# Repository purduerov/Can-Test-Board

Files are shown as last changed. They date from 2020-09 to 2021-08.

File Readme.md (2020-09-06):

# Readme for Can-Test-Board

Whenever you make a new part, download the datasheet and save it here _**and**_ with the part in the parts library

Always pull other people's changes before beginning to work
`git pull`

Be sure to push your changes after  working on them. Run:
1. `git add .` to add any files in this directory or a subdirectory
or `git add -u` to add any modified files
2. (Optional) `git clean -nX` to see what ignored files can be removed
	`git clean -fX` removes ignored files (Eagle backups)
3. `git commit -m "helpful commit message"` with a description of the work that you did
4. `git push` to push your work to github

Other helpful commands
* `git status` says information about modified and staged files
* `git log` shows the recent commits of the repository
* `git log filename.extension` show the recent commits for just that file
* `git checkout first-couple-letter-of-commit-id` lets you go back to a previous version
* `git checkout master` brings you back to the latest commit
* `git tag` lists the tags
* `git tag -a orderX -m "the version of the board placed for the X'th order"` tag a specific commit
* `git push --tags` needed to push tags to remote
* `git show orderX` show the commit log for the given tag
* `git checkout orderX` go back and interact with the files at the tagged commit

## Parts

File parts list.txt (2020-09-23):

Partlist

Exported from CAN-Test-Board.brd at 9/23/2020 9:46 AM

EAGLE Version 9.6.2 Copyright (c) 1988-2020 Autodesk, Inc.

Assembly variant: 

Part     Value          Package          Library                   Position (mil)        Orientation

C1       4.7uF          0603             SparkFun-Capacitors       (810 860)             MR270
C2       4.7uF          0603             SparkFun-Capacitors       (590 690)             MR90
C3       4.7uF          0603             SparkFun-Capacitors       (590 860)             MR270
C4       4.7uF          0603             SparkFun-Capacitors       (660 860)             MR270
C5       4.7uF          0603             SparkFun-Capacitors       (740 860)             MR270
C6       4.7uF          0603             SparkFun-Capacitors       (660 690)             MR90
C7       4.7uF          0603             SparkFun-Capacitors       (840 340)             MR180
C8       4.7uF          0603             SparkFun-Capacitors       (980 1160)            R0
C9       4.7uF          0603             SparkFun-Capacitors       (550 1160)            R180
C10      4.7uF          0603             SparkFun-Capacitors       (1160 1080)           MR270
C11      0.1uF          0603             SparkFun-Capacitors       (1120 1230)           R90
C12      100nF          0603             SparkFun-Capacitors       (700 1990)            MR90
C13      18pF           CAP_0603         Resistor_Capacitor        (1350 1870)           R270
C14      18pF           CAP_0603         Resistor_Capacitor        (1350 1440)           R90
C15      100nF          0603             SparkFun-Capacitors       (890 1480)            MR90
C16      4.7nF          0603             SparkFun-Capacitors       (1670 910)            MR270
C17      1.0uF          0603             SparkFun-Capacitors       (1620 1240)           R0
C18      1.0uF          0603             SparkFun-Capacitors       (1770 1320)           R90
D1                      LED-0603         SparkFun-LED              (1110 150)            R270
D2                      LED-0603         SparkFun-LED              (1010 150)            R270
J1                      1X12             SparkFun-Connectors       (90 100)              R90
J2                      1X12             SparkFun-Connectors       (1960 1190)           R270
J3                      1X05             SparkFun-Connectors       (370 1640)            R90
J4                      1X03             SparkFun-Connectors       (210 1570)            R270
J5                      1X03             SparkFun-Connectors       (80 1570)             R270
PCB1     RPI2           RPI2             MicrocontrollerComponents (2310 4300)           R180
R1       1k             0603             SparkFun-Resistors        (740 1120)            R270
R2       1k             0603             SparkFun-Resistors        (810 230)             MR270
R3       1k             0603             SparkFun-Resistors        (800 1120)            R270
R4       0              0603             SparkFun-Resistors        (1210 1750)           R180
R5       0              0603             SparkFun-Resistors        (640 1530)            R90
R6       60             0603             SparkFun-Resistors        (1640 1050)           MR0
R7       330            0603             SparkFun-Resistors        (1110 300)            R90
R8       60             0603             SparkFun-Resistors        (1640 1130)           MR180
R9       330            0603             SparkFun-Resistors        (1010 310)            R90
R10      60             0603             SparkFun-Resistors        (1010 1270)           R180
R11      60             0603             SparkFun-Resistors        (1010 1350)           R0
R12      10k            0603             SparkFun-Resistors        (1730 1450)           R180
R13      10k            0603             SparkFun-Resistors        (1730 1520)           R180
R14      0              0603             SparkFun-Resistors        (1480 1310)           R0
R15      0              0603             SparkFun-Resistors        (1730 1640)           R270
R19      0              0603             SparkFun-Resistors        (1210 1560)           R180
RESET                   SW_2512          DiscreteComponents        (610 350)             R0
SV1                     FE05-1           con-lsta                  (510 120)             R180
U$1      MCP2515        MCP2515          PI_Shield_Library         (1100 1660)           R90
U$2      TCAN337D       TCAN337D         PI_Shield_Library         (800 1560)            MR270
U$3      STM32F042K6T6  STM32F042K6T6    PI_Shield_Library         (590 940)             R270
U$4      T2I            T2I              Samtec t2i                (1880 240)            R180
U$5      NCP114         TSOP-5           LED_lib                   (1680 1380)           R270
U$8      TCAN337D       TCAN337D         PI_Shield_Library         (1270 1160)           MR180
Y1       ECS-80-S-4X    XTAL_ECS-80-S-4X ECS-80-S-4X               (770 1160)            MR0
Y2       ECS-80-S-4X    XTAL_ECS-80-S-4X ECS-80-S-4X               (1350 1660)           MR90

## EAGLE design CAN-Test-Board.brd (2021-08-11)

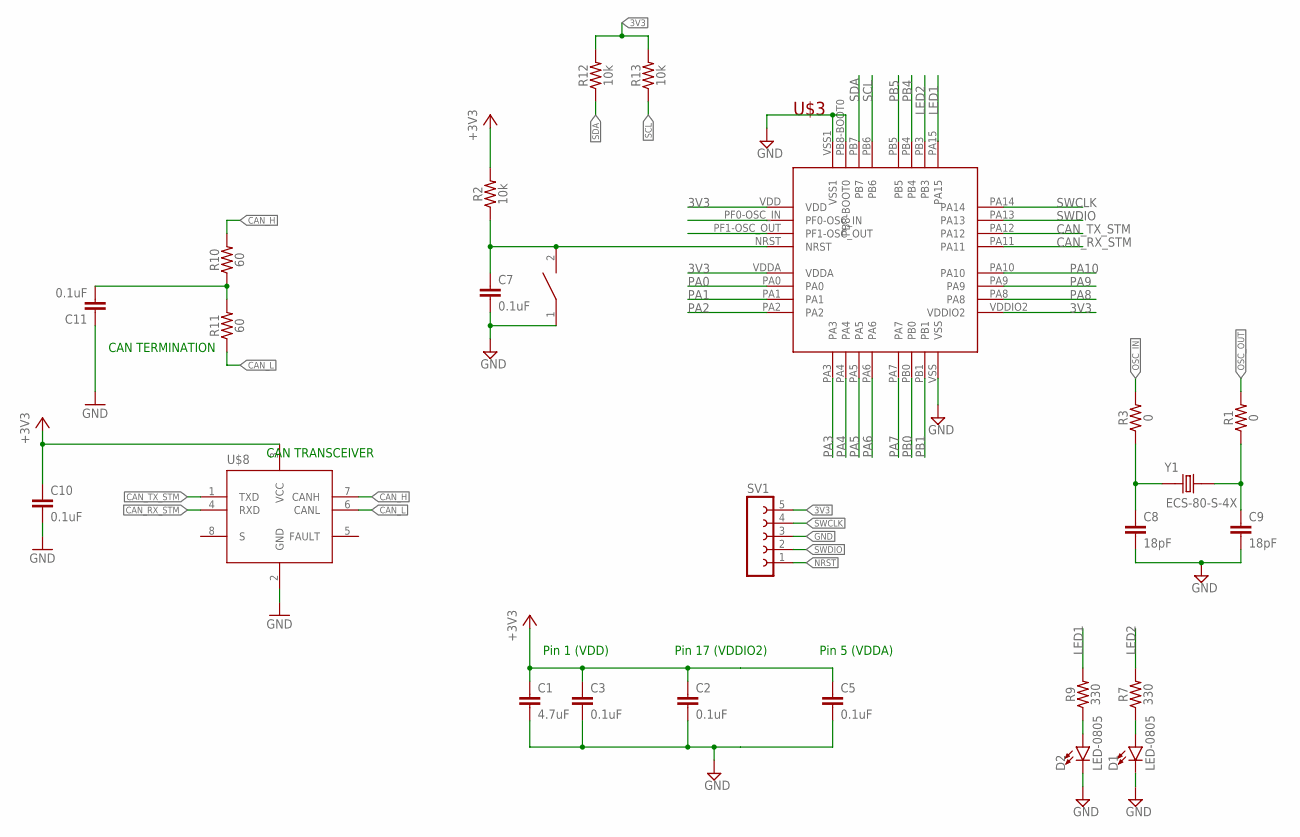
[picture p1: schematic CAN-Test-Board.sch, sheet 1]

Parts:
C1: 4.7uF; 0603
C2, C3, C5, C7, C10, C11: 0.1uF; 0603
C8, C9: 18pF; 0603
D1, D2: LED-0805; 0805
R1, R3: 0; 0603
R2, R12, R13: 10k; 0603
R7, R9: 330; 0603
R10, R11: 60; 0603
RESET: DISCRETECOMPONENTS_SWITCH; DISCRETECOMPONENTS_SW_2512
SV1: FE05-1
U$3: STM32F042K6T6
U$8: TCAN337D; SOIC-8
Y1: ECS-80-S-4X; XTAL_ECS-80-S-4X

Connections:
3V3: C1.1, C2.1, C3.1, C5.1, C10.1, R2.2, R12.2, R13.2, SV1.5, U$3.VDD, U$3.VDDA, U$3.VDDIO2, U$8.3 (VCC); also elsewhere on the board
CAN_H: R10.2, U$8.7 (CANH); also elsewhere on the board
CAN_L: R11.1, U$8.6 (CANL); also elsewhere on the board
CAN_RX_STM: U$3.PA11, U$8.4 (RXD)
CAN_TX_STM: U$3.PA12, U$8.1 (TXD)
GND: C1.2, C2.2, C3.2, C5.2, C7.2, C8.2, C9.2, C10.2, C11.1, D1.C, D2.C, RESET.1, SV1.3, U$3.PB8-BOOT0, U$3.VSS, U$3.VSS1, U$8.2 (GND); also elsewhere on the board
LED1: R9.2, U$3.PA15
LED2: R7.2, U$3.PB3; also elsewhere on the board
unnamed: C9.1, R1.1, Y1.2
unnamed: C8.1, R3.1, Y1.1
unnamed: C11.2, R10.1, R11.2
unnamed: D2.A, R9.1
unnamed: D1.A, R7.1
NRST: C7.1, R2.1, RESET.2, SV1.1, U$3.NRST
OSC_IN: R3.2, U$3.PF0-OSC_IN
OSC_OUT: R1.2, U$3.PF1-OSC_OUT
PA0: U$3.PA0; also elsewhere on the board
PA1: U$3.PA1; also elsewhere on the board
PA2: U$3.PA2; also elsewhere on the board
PA3: U$3.PA3; also elsewhere on the board
PA4: U$3.PA4; also elsewhere on the board
PA5: U$3.PA5; also elsewhere on the board
PA6: U$3.PA6; also elsewhere on the board
PA7: U$3.PA7; also elsewhere on the board
PA8: U$3.PA8; also elsewhere on the board
PA9: U$3.PA9; also elsewhere on the board
PA10: U$3.PA10; also elsewhere on the board
PB0: U$3.PB0; also elsewhere on the board
PB1: U$3.PB1; also elsewhere on the board
PB4: U$3.PB4; also elsewhere on the board
PB5: U$3.PB5; also elsewhere on the board
SCL: R13.1, U$3.PB6; also elsewhere on the board
SDA: R12.1, U$3.PB7; also elsewhere on the board
SWCLK: SV1.4, U$3.PA14
SWDIO: SV1.2, U$3.PA13

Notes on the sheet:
CAN TRANSCEIVER
CAN TERMINATION
Pin 1 (VDD)
Pin 17 (VDDIO2)
Pin 5 (VDDA)

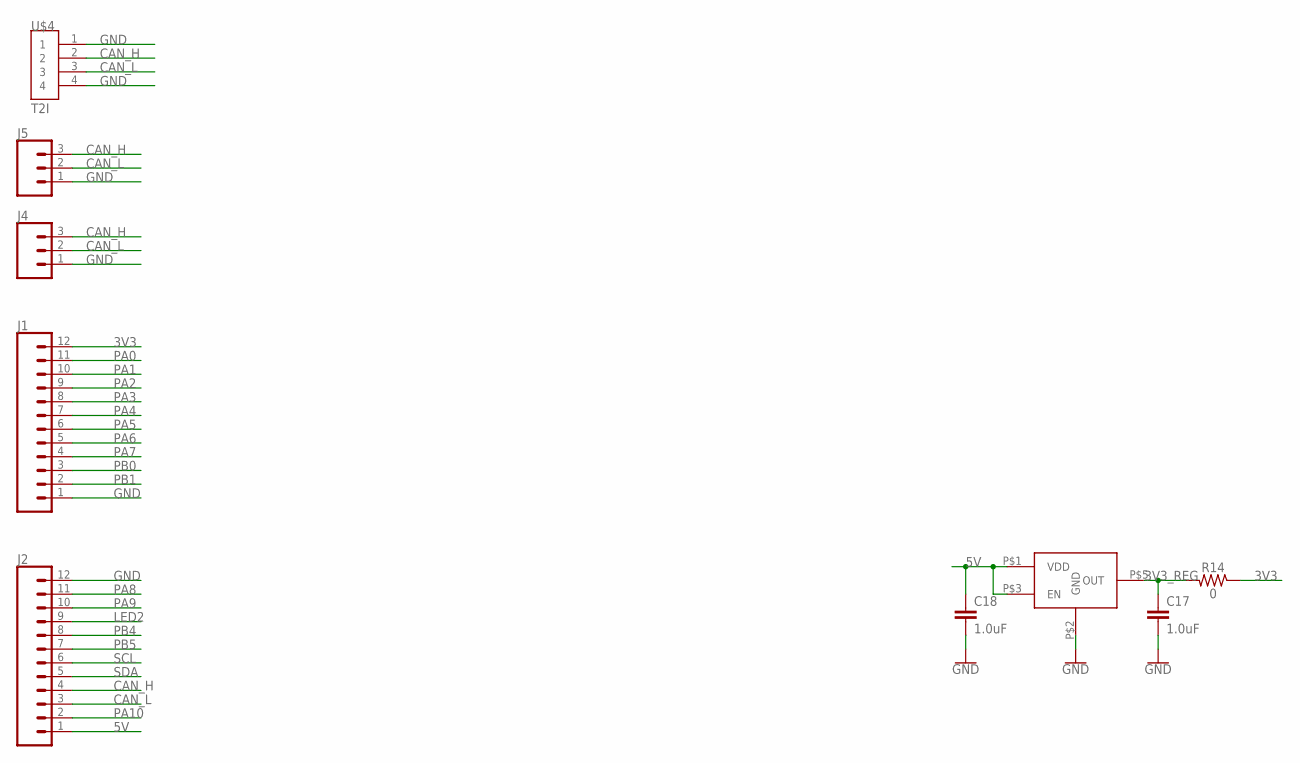
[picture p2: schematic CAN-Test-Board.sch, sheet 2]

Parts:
C17, C18: 1.0uF; 0603
J1, J2: CONN_12; 1X12
J4, J5: CONN_03; 1X03
R14: 0; 0603
U$4: T2I
U$5: NCP114; TSOP-5

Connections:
3V3: J1.12, R14.1; also elsewhere on the board
3V3_REG: C17.1, R14.2, U$5.P$5 (OUT)
5V: C18.1, J2.1, U$5.P$1 (VDD), U$5.P$3 (EN); also elsewhere on the board
CAN_H: J2.4, J4.3, J5.3, U$4.2; also elsewhere on the board
CAN_L: J2.3, J4.2, J5.2, U$4.3; also elsewhere on the board
GND: C17.2, C18.2, J1.1, J2.12, J4.1, J5.1, U$4.1, U$4.4, U$5.P$2 (GND); also elsewhere on the board
LED2: J2.9; also elsewhere on the board
PA0: J1.11; also elsewhere on the board
PA1: J1.10; also elsewhere on the board
PA2: J1.9; also elsewhere on the board
PA3: J1.8; also elsewhere on the board
PA4: J1.7; also elsewhere on the board
PA5: J1.6; also elsewhere on the board
PA6: J1.5; also elsewhere on the board
PA7: J1.4; also elsewhere on the board
PA8: J2.11; also elsewhere on the board
PA9: J2.10; also elsewhere on the board
PA10: J2.2; also elsewhere on the board
PB0: J1.3; also elsewhere on the board
PB1: J1.2; also elsewhere on the board
PB4: J2.8; also elsewhere on the board
PB5: J2.7; also elsewhere on the board
SCL: J2.6; also elsewhere on the board
SDA: J2.5; also elsewhere on the board

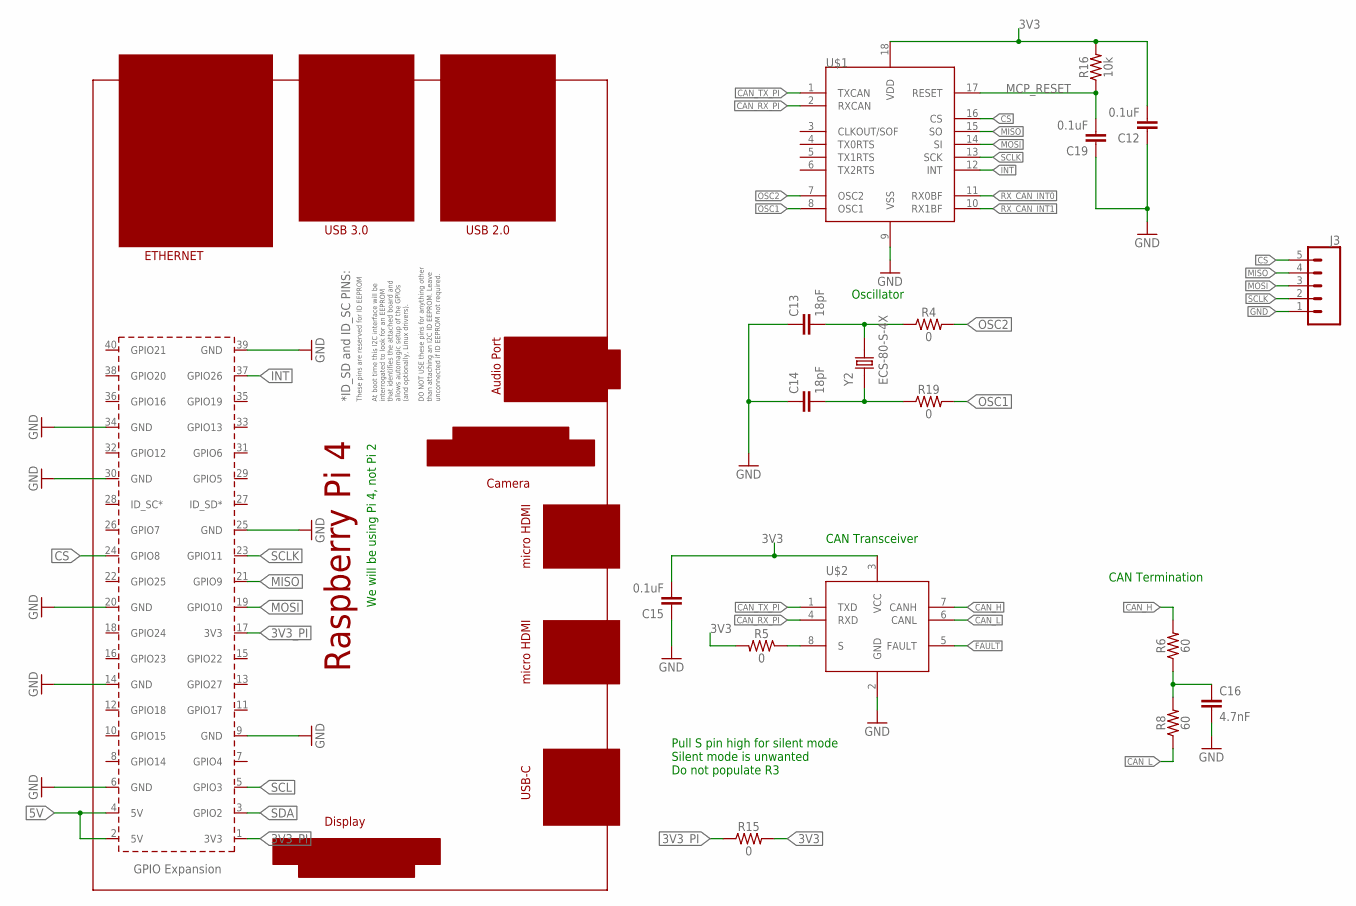
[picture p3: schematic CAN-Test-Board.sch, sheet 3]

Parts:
C12, C15, C19: 0.1uF; 0603
C13, C14: 18pF; 0603
C16: 4.7nF; 0603
J3: CONN_05; 1X05
PCB1: RPI4
R4, R5, R15, R19: 0; 0603
R6, R8: 60; 0603
R16: 10k; 0603
U$1: MCP2515; SOIC-18
U$2: TCAN337D; SOIC-8
Y2: ECS-80-S-4X; XTAL_ECS-80-S-4X

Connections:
3V3: C12.2, C15.2, R5.2, R15.2, R16.2, U$1.18 (VDD), U$2.3 (VCC); also elsewhere on the board
3V3_PI: PCB1.1 (3V3), PCB1.17 (3V3), R15.1
5V: PCB1.2 (5V), PCB1.4 (5V); also elsewhere on the board
CAN_H: R6.2, U$2.7 (CANH); also elsewhere on the board
CAN_L: R8.1, U$2.6 (CANL); also elsewhere on the board
CAN_RX_PI: U$1.2 (RXCAN), U$2.4 (RXD)
CAN_TX_PI: U$1.1 (TXCAN), U$2.1 (TXD)
CS: J3.5, PCB1.24 (GPIO8), U$1.16 (CS)
FAULT: U$2.5 (FAULT)
GND: C12.1, C13.1, C14.1, C15.1, C16.2, C19.1, J3.1, PCB1.6 (GND), PCB1.9 (GND), PCB1.14 (GND), PCB1.20 (GND), PCB1.25 (GND), PCB1.30 (GND), PCB1.34 (GND), PCB1.39 (GND), U$1.9 (VSS), U$2.2 (GND); also elsewhere on the board
INT: PCB1.37 (GPIO26), U$1.12 (INT)
MCP_RESET: C19.2, R16.1, U$1.17 (RESET)
MISO: J3.4, PCB1.21 (GPIO9), U$1.15 (SO)
MOSI: J3.3, PCB1.19 (GPIO10), U$1.14 (SI)
unnamed: C16.1, R6.1, R8.2
OSC1: R19.2, U$1.8 (OSC1)
OSC2: R4.2, U$1.7 (OSC2)
OSC_1_MID: C14.2, R19.1, Y2.1
OSC_2_MID: C13.2, R4.1, Y2.2
RX_CAN_INT0: U$1.11 (RX0BF)
RX_CAN_INT1: U$1.10 (RX1BF)
SCL: PCB1.5 (GPIO3); also elsewhere on the board
SCLK: J3.2, PCB1.23 (GPIO11), U$1.13 (SCK)
SDA: PCB1.3 (GPIO2); also elsewhere on the board
SILENT_PI: R5.1, U$2.8 (S)

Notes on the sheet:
Oscillator
CAN Transceiver
CAN Termination
Pull S pin high for silent mode Silent mode is unwanted Do not populate R3
We will be using Pi 4, not Pi 2

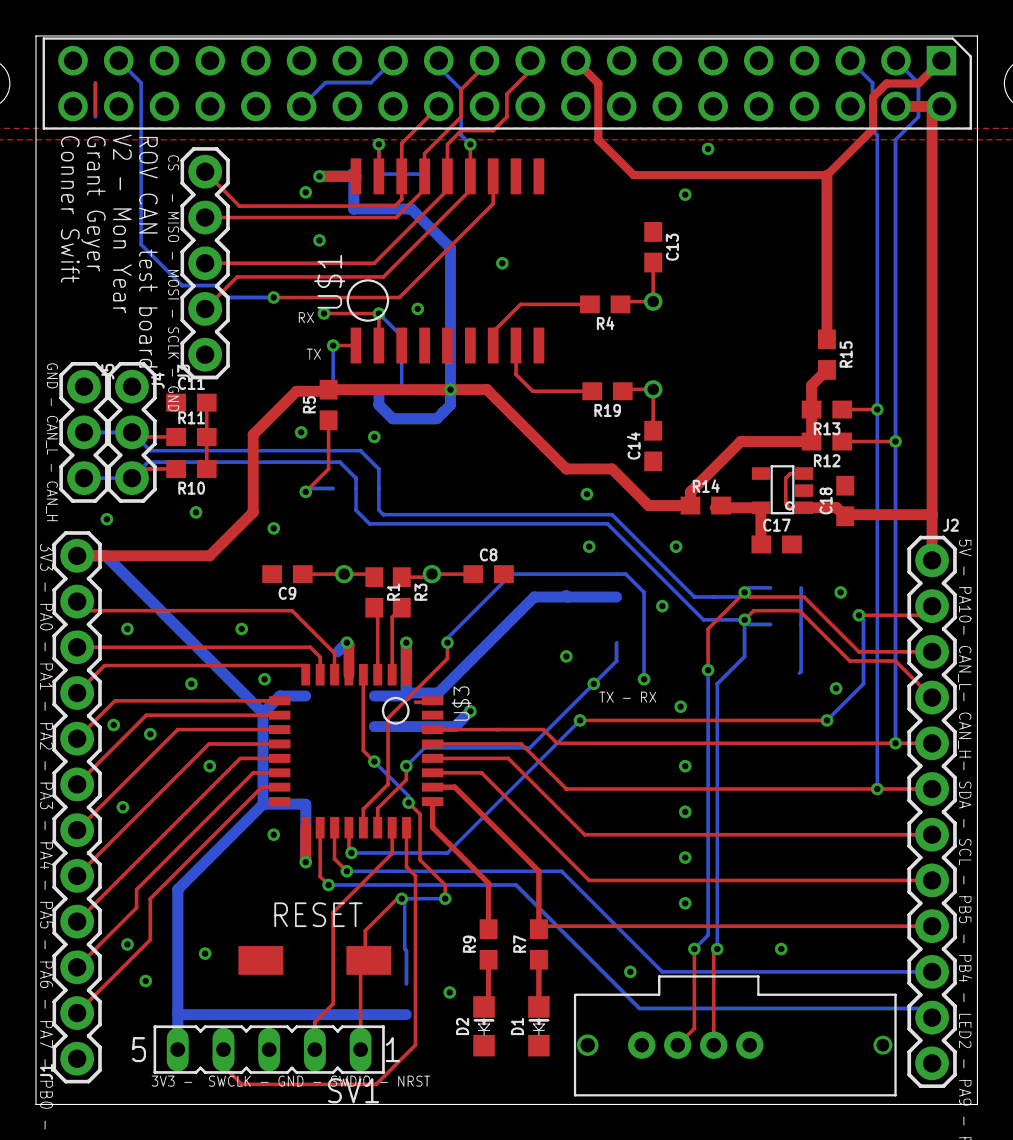
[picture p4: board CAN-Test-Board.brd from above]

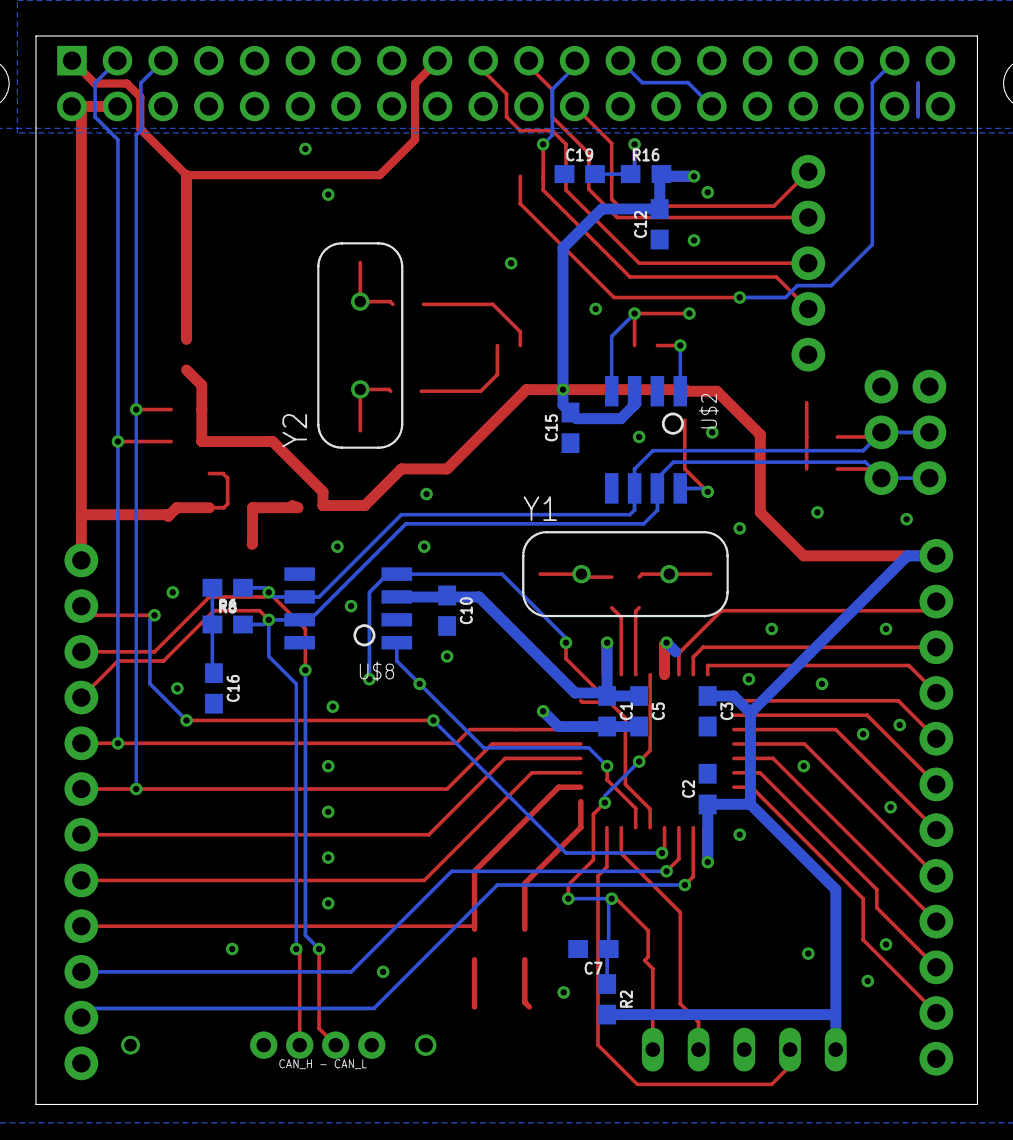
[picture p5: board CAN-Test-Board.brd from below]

Board: 2 copper layers, 52.3 x 59.4 mm, 52 parts (18 on the bottom side), 52 nets.

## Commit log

2020-09-05 first design
    [CAN-Test-Board.brd, CAN-Test-Board.sch]
2020-09-08 smaller and extra CAN breakouts
    [CAN-Test-Board.brd, CAN-Test-Board.sch]
2020-09-09 labels and 3v3 power options
    [CAN-Test-Board.brd, CAN-Test-Board.sch]
2020-09-12 added samtec t2i
    [CAN-Test-Board.brd, CAN-Test-Board.sch]
2020-09-13 little better CAN trace routing around PI transceiver
    [CAN-Test-Board.brd]
2020-09-23 changed schematic to pages
    [CAN-Test-Board.sch]
2020-09-23 couple part values
    [CAN-Test-Board.brd, CAN-Test-Board.sch]
2020-10-13 couple changes for a possible rev 2 (led sizes, button footprint)
    [CAN-Test-Board.brd, CAN-Test-Board.sch]
2021-04-03 Shorted Reset to 3V3 instead of leaving it floating
    [CAN-Test-Board.brd, CAN-Test-Board.sch]
2021-05-20 Add missing interrupt connection
    [CAN-Test-Board.brd, CAN-Test-Board.sch]
2021-08-11 Update parts and values. Fix missing connection?
    [CAN-Test-Board.brd, CAN-Test-Board.sch]

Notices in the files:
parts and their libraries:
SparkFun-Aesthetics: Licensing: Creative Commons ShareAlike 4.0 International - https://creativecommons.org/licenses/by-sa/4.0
